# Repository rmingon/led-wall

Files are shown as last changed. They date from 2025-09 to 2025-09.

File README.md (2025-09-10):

# LED-Wall Tile — CH32V003 Parallel-Bus WS2812B Controller (5×5)

A modular **5×5 WS2812B LED tile** driven by a **CH32V003** slave MCU.  
Tiles share a simple **8-bit parallel bus + CLK + EN** so a Raspberry Pi (or any MCU) can address many tiles and push pixel data quickly.

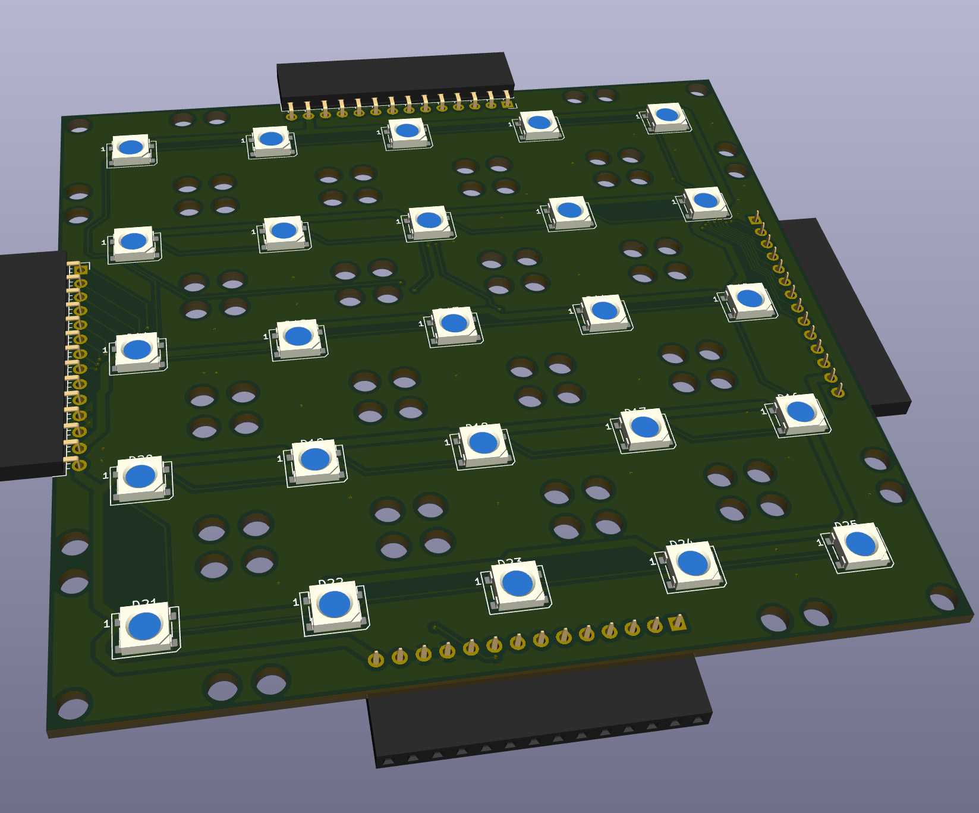
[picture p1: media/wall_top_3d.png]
3d

---

## Highlights

- **25× WS2812B** per tile (5 rows × 5 columns), daisy-chained on-board
- **Parallel control bus:** `DATA0…DATA7`, `CLK`, `EN`, optional `RST`
- **MCU:** WCH **CH32V003F…** (RISC-V, 3.3 V)
- **Power:** 5 V input for LEDs; onboard **AMS1117-3.3** LDO for the MCU
- **Connectors on four edges** for tiling/rotation; pass-through for power & bus
- **Status LED** on a GPIO for quick diagnostics
- Designed with **KiCad 9.0.3**

---

## Repo structure

```
/wall/
  wall.kicad_pro
  wall.kicad_pcb
  wall.kicad_sch
  wall.kicad_prl
/media/
  wall_top_3d.jpeg
  wall_bottom_3d.jpeg
  wall_pcb.png
  wall_schematic.png
/firmware/        # (placeholder) CH32V003 code
/tools/           # (placeholder) host examples (Raspberry Pi)
README.md
```

---

## Images

- Top 3D: `media/wall_top_3d.jpeg`
- Bottom 3D: `media/wall_bottom_3d.jpeg`
- PCB layout: `media/wall_pcb.png`
- Schematic: `media/wall_schematic.png`

---

## Electrical overview

- **LED matrix:** 25 × WS2812B (5050). Data is routed serpentine per row.
- **MCU:** `CH32V003F*P6` (labelled **U1** in the schematic).
  - Parallel data bus on **PC0…PC7**
  - `CLK` and `EN` on PDx pins (see net labels in schematic)
  - `PA1/PA2` used for the **WS2812** data output to the first LED in the chain
  - `RST` net broken out (optional external reset)
- **Power:**
  - **+5 V** for LEDs
  - **AMS1117-3.3** (U3) generates **+3V3** for the MCU; C1/C2/C3 for decoupling
- **Indicators:** D26 + R4 connected to a GPIO (status / heartbeat)

> ⚠️ **Current budget:** Each WS2812B can draw up to **40 mA** at full-white.  
> One tile worst-case ≈ **25 × 40 mA = 1.5 A @ 5 V** (plus margin).  
> Size your power rails accordingly and avoid sustained full-white if thermals are tight.

---

## Connectors / Pinout

Each edge header is a **1×14** connector carrying power and the parallel bus.

| Pin | Signal | Notes |
| --: | :----- | :--- |
| 1 | DATA0  | Parallel data bit 0 (MCU **PC0**)  |
| 2 | DATA1  | (PC1) |
| 3 | DATA2  | (PC2) |
| 4 | DATA3  | (PC3) |
| 5 | DATA4  | (PC4) |
| 6 | DATA5  | (PC5) |
| 7 | DATA6  | (PC6) |
| 8 | DATA7  | (PC7) |
| 9 | CLK | Rising edge latch (EXTI7_0 IRQ) |
|  10 | EN | Tile enable / latch (PDx) |
|  11 | GND | Ground |
|  12 | GND | Ground (second pin for current) |
|  13 | +5V | LED power |
|  14 | +5V | LED power (second pin for current) |

> Exact PDx assignments are labelled in the schematic nets; keep those in firmware defines so you can move them if the footprint changes.

- WS2812 data → **PC7 / TIM2_CH2 (remap)**
- Driven by **TIM2 PWM + DMA**

---

## Protocol

Each frame is transmitted as a sequence of **bytes** clocked on **PD2 rising edge** while the slave samples D0–D7.

**Frame format:**

```
SOF0 SOF1 ADDR CMD LEN PAY[LEN] CRC
```

- **SOF0** = `0xA5`
- **SOF1** = `0x5A`
- **ADDR** = 0–254 for unicast, `0xFF` for broadcast
- **CMD** = command byte
- **LEN** = number of payload bytes
- **PAY** = payload
- **CRC** = Dallas/Maxim CRC8 (poly=0x31 reflected=0x8C, init=0x00) computed over `ADDR..CMD..LEN..PAY`

### Commands

| CMD  | Name | LEN | Payload description |
| ---- | --- | --- | --- |
| 0x01 | `SET_ALL_RGB` | 3×N (75) | [R,G,B] triplets for all LEDs |
| 0x02 | `SET_ONE_RGB` | 4 | [index, R, G, B] (0–24 index) |
| 0x03 | `FILL_RGB` | 3 | [R, G, B] fill all LEDs |
| 0x04 | `BOOT_TEST` | 0 | Run built-in RGB test animation |

---

## Firmware (CH32V003)

- **Toolchain:** WCH-RISC-V (MounRiver) or Open-source (e.g., `riscv-none-elf-gcc` + `openocd` for WCH-LinkE).
- **Peripherals used:**
  - GPIO for `DATA[7:0]`, `CLK`, `EN`, `LED`
  - Timer or edge-detect to sample `CLK` while `EN=1`
  - Bit-banged or timer-driven WS2812 waveform output on `PAx`
- **WS2812 timing:** 800 kHz, 1.25 µs/bit. Use a timer and tight ISR/DMA-like loop to meet timing.

**Build steps (outline):**

1. Clone repo; open `/kicad/wall.kicad_pro` to view hardware.
2. Open `/wall_code/` in your IDE; set your tile address in `main.c`.
3. Flash with **WCH-LinkE** via **SWIO** (PD1 on CH32V003). Provide a small 3-pin tag-connector or pogo-pads on your programmer.
4. Power at 5 V and verify the heartbeat LED.

---

## Example Host Frame

Set all 25 LEDs to **red (255,0,0)**:

```
A5 5A 12 01 4B  FF 00 00 FF 00 00 ... (25 triplets) ... CRC
```

- `0xA5 0x5A` = SOF
- `0x12` = target address
- `0x01` = `SET_ALL_RGB`
- `0x4B` = 75 payload bytes
- Payload = 25× [FF,00,00]
- `CRC` = computed over ADDR..PAYLOAD

## Raspberry Pi example (Python, pseudo-code)

2. Open `host.py` in your IDE.

## Example Host Frame

Set all 25 LEDs to **red (255,0,0)**:

```
A5 5A 12 01 4B  FF 00 00 FF 00 00 ... (25 triplets) ... CRC
```

- `0xA5 0x5A` = SOF
- `0x12` = target address
- `0x01` = `SET_ALL_RGB`
- `0x4B` = 75 payload bytes
- Payload = 25× [FF,00,00]
- `CRC` = computed over ADDR..PAYLOAD

---

## Manufacturing notes

- **Layers:** 2-layer, 1.6 mm FR-4, 1 oz Cu
- **Min track/clearance:** per your fab defaults (design uses moderate widths)
- **Finish:** HASL or ENIG
- **Decoupling:** place 0.1 µF near the MCU VDD and each LED power rail segment
- **Mounting:** corner holes + through-grid holes in the LED field (for diffusion/weight).

---

## Bring-up checklist

1. Power at **5 V** and check **+3V3** out of U3 (AMS1117-3.3).
2. Flash firmware; confirm status LED blinks.
3. With a logic analyzer, verify `CLK` edges and that `DATA[7:0]` are stable at each edge while `EN=1`.
4. Send a **Fill** command to a single address → tile lights uniformly.
5. Push a full **75-byte** pixel buffer → verify 5×5 order matches your mapping.

---

## License

- Hardware: CC-BY-SA 4.0
- Firmware/Host code: MIT

---

## Credits

Designed by **RMINGON**.  
KiCad project files: `kicad/wall.*` (created with KiCad **9.0.3**).

---

### Bill-of-Materials (core)

| Ref | Part | Notes |
| --- | --- | --- |
| U1 | **CH32V003F…P6** | 3.3 V RISC-V MCU |
| U3 | **AMS1117-3.3** | 5 V → 3.3 V LDO |
| D1–D25  | **WS2812B** | 5 V addressable LEDs |
| D26, R4 | Status LED + 5 Ω–1 kΩ | (value per brightness; schematic shows **R4 5 Ω**) |
| J1–J4 | 1×14 headers | Bus + Power |
| C1–C3 | 10 µF/0.1 µF mix | Regulator & MCU decoupling |

> Tweak values to match your inventory and regulator stability requirements (e.g., AMS1117 likes ≥10 µF on input/output).

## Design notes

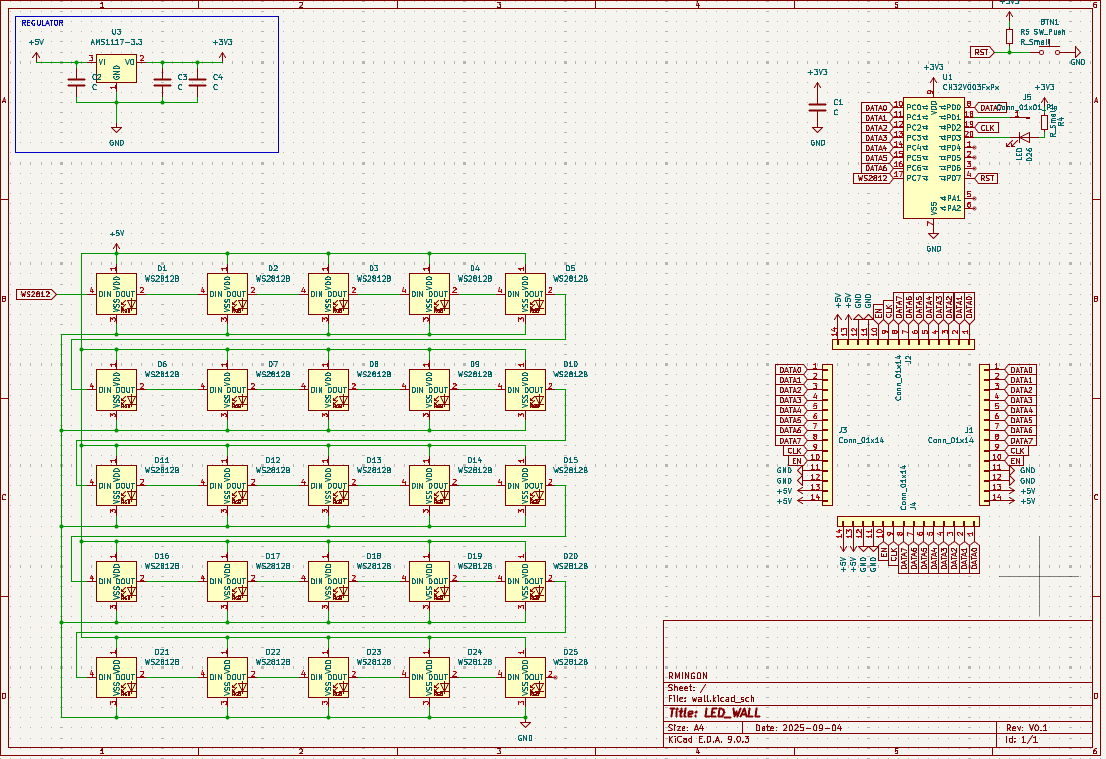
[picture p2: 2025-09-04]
media/wall_schematic.png

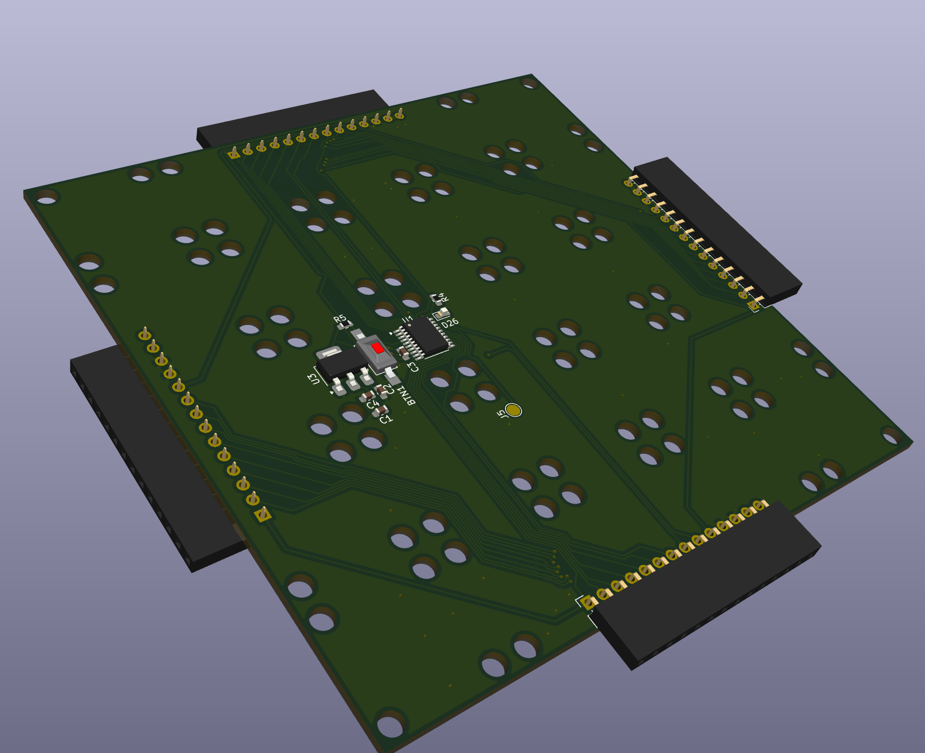
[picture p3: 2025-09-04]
media/wall_bottom_3d.png

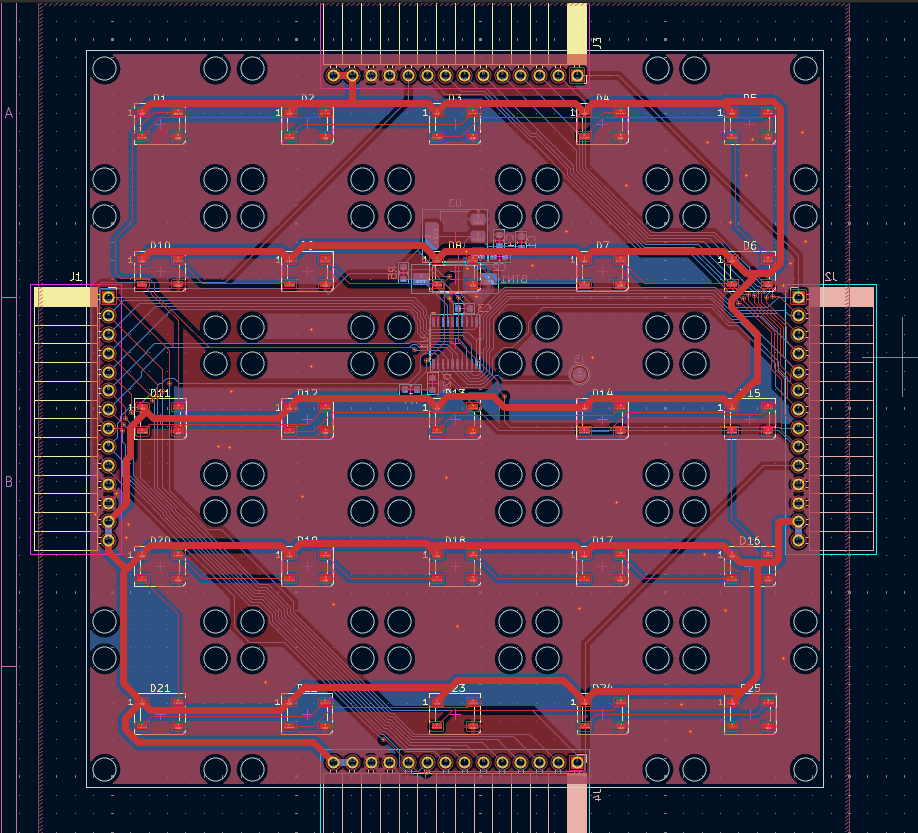
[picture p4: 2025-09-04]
media/wall_pcb.png

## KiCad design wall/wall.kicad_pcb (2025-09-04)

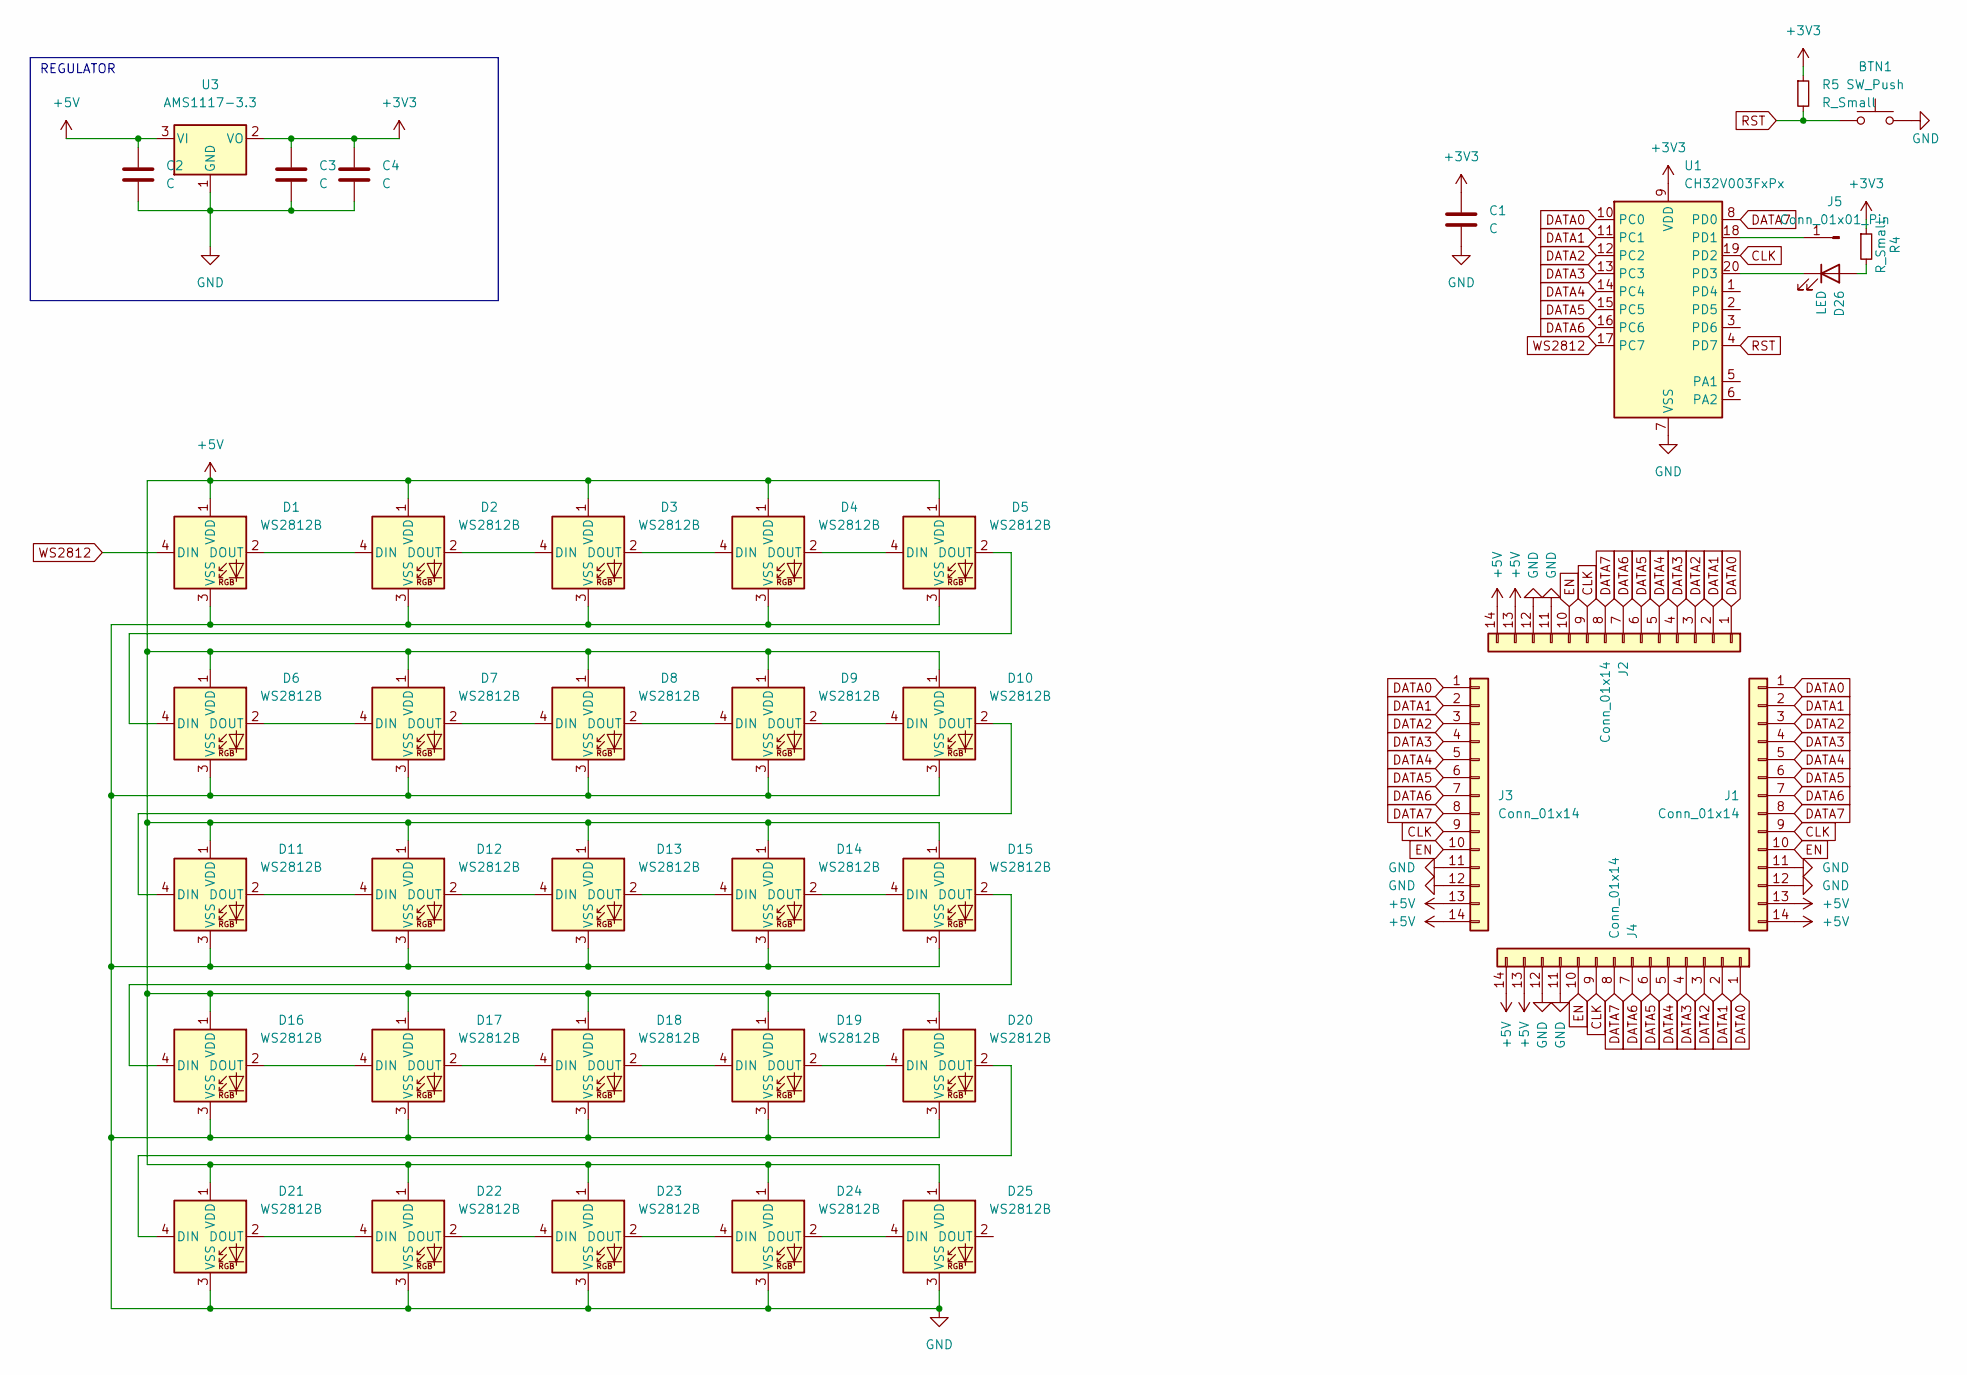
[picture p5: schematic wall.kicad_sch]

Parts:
BTN1: SW_Push; SW_SPST_FSMSM; LCSC C398053
C1, C2, C4: C; C_0603_1608Metric; LCSC C30926
C3: C; C_0603_1608Metric; LCSC C19702
D1, D2, D3, D4, D5, D6, D7, D8, D9, D10, D11, D12, D13, D14, D15, D16, D17, D18, D19, D20, D21, D22, D23, D24, D25: WS2812B; LED_WS2812B_PLCC4_5.0x5.0mm_P3.2mm
D26: LED; LED_0603_1608Metric; LCSC C19171301
J1, J2, J3, J4: Conn_01x14; PinSocket_1x14_P2.54mm_Horizontal
J5: Conn_01x01_Pin; TestPoint_Pad_D2.0mm
R4: R_Small; R_0603_1608Metric; LCSC C2906975
R5: R_Small; R_0603_1608Metric; LCSC C98220
U1: CH32V003FxPx; TSSOP-20_4.4x6.5mm_P0.65mm
U3: AMS1117-3.3; SOT-223-3_TabPin2; LCSC C6186

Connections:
+3V3: C1.1, C3.1, C4.1, R4.1, R5.1, U1.9 (VDD), U3.2 (VO)
+5V: C2.1, D1.1 (VDD), D2.1 (VDD), D3.1 (VDD), D4.1 (VDD), D5.1 (VDD), D6.1 (VDD), D7.1 (VDD), D8.1 (VDD), D9.1 (VDD), D10.1 (VDD), D11.1 (VDD), D12.1 (VDD), D13.1 (VDD), D14.1 (VDD), D15.1 (VDD), D16.1 (VDD), D17.1 (VDD), D18.1 (VDD), D19.1 (VDD), D20.1 (VDD), D21.1 (VDD), D22.1 (VDD), D23.1 (VDD), D24.1 (VDD), D25.1 (VDD), J1.13, J1.14, J2.13, J2.14, J3.13, J3.14, J4.13, J4.14, U3.3 (VI)
CLK: J1.9, J2.9, J3.9, J4.9, U1.19 (PD2)
DATA0: J1.1, J2.1, J3.1, J4.1, U1.10 (PC0)
DATA1: J1.2, J2.2, J3.2, J4.2, U1.11 (PC1)
DATA2: J1.3, J2.3, J3.3, J4.3, U1.12 (PC2)
DATA3: J1.4, J2.4, J3.4, J4.4, U1.13 (PC3)
DATA4: J1.5, J2.5, J3.5, J4.5, U1.14 (PC4)
DATA5: J1.6, J2.6, J3.6, J4.6, U1.15 (PC5)
DATA6: J1.7, J2.7, J3.7, J4.7, U1.16 (PC6)
DATA7: J1.8, J2.8, J3.8, J4.8, U1.8 (PD0)
EN: J1.10, J2.10, J3.10, J4.10
GND: BTN1.2, C1.2, C2.2, C3.2, C4.2, D1.3 (VSS), D2.3 (VSS), D3.3 (VSS), D4.3 (VSS), D5.3 (VSS), D6.3 (VSS), D7.3 (VSS), D8.3 (VSS), D9.3 (VSS), D10.3 (VSS), D11.3 (VSS), D12.3 (VSS), D13.3 (VSS), D14.3 (VSS), D15.3 (VSS), D16.3 (VSS), D17.3 (VSS), D18.3 (VSS), D19.3 (VSS), D20.3 (VSS), D21.3 (VSS), D22.3 (VSS), D23.3 (VSS), D24.3 (VSS), D25.3 (VSS), J1.11, J1.12, J2.11, J2.12, J3.11, J3.12, J4.11, J4.12, U1.7 (VSS), U3.1 (GND)
unnamed: D1.2 (DOUT), D2.4 (DIN)
unnamed: D2.2 (DOUT), D3.4 (DIN)
unnamed: D3.2 (DOUT), D4.4 (DIN)
unnamed: D4.2 (DOUT), D5.4 (DIN)
unnamed: D5.2 (DOUT), D6.4 (DIN)
unnamed: D6.2 (DOUT), D7.4 (DIN)
unnamed: D7.2 (DOUT), D8.4 (DIN)
unnamed: D8.2 (DOUT), D9.4 (DIN)
unnamed: D9.2 (DOUT), D10.4 (DIN)
unnamed: D10.2 (DOUT), D11.4 (DIN)
unnamed: D11.2 (DOUT), D12.4 (DIN)
unnamed: D12.2 (DOUT), D13.4 (DIN)
unnamed: D13.2 (DOUT), D14.4 (DIN)
unnamed: D14.2 (DOUT), D15.4 (DIN)
unnamed: D15.2 (DOUT), D16.4 (DIN)
unnamed: D16.2 (DOUT), D17.4 (DIN)
unnamed: D17.2 (DOUT), D18.4 (DIN)
unnamed: D18.2 (DOUT), D19.4 (DIN)
unnamed: D19.2 (DOUT), D20.4 (DIN)
unnamed: D20.2 (DOUT), D21.4 (DIN)
unnamed: D21.2 (DOUT), D22.4 (DIN)
unnamed: D22.2 (DOUT), D23.4 (DIN)
unnamed: D23.2 (DOUT), D24.4 (DIN)
unnamed: D24.2 (DOUT), D25.4 (DIN)
unnamed: D26.2 (A), R4.2
unnamed: D26.1 (K), U1.20 (PD3)
unnamed: J5.1, U1.18 (PD1)
RST: BTN1.1, R5.2, U1.4 (PD7)
WS2812: D1.4 (DIN), U1.17 (PC7)

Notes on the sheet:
REGULATOR

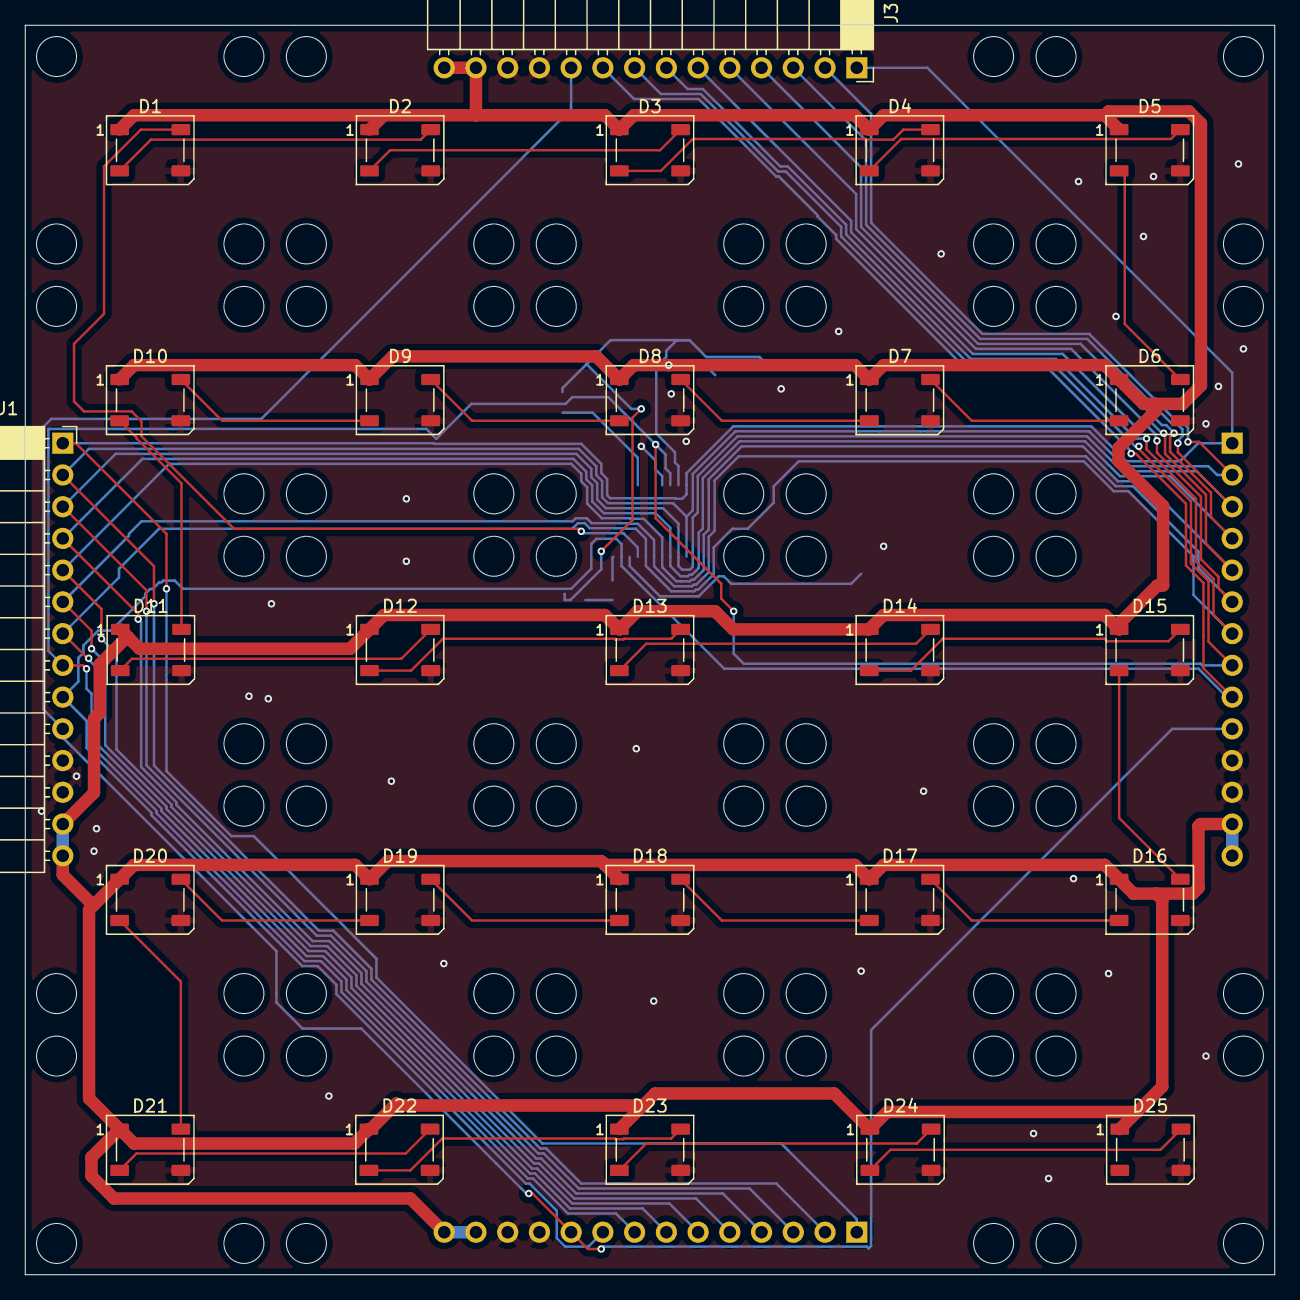
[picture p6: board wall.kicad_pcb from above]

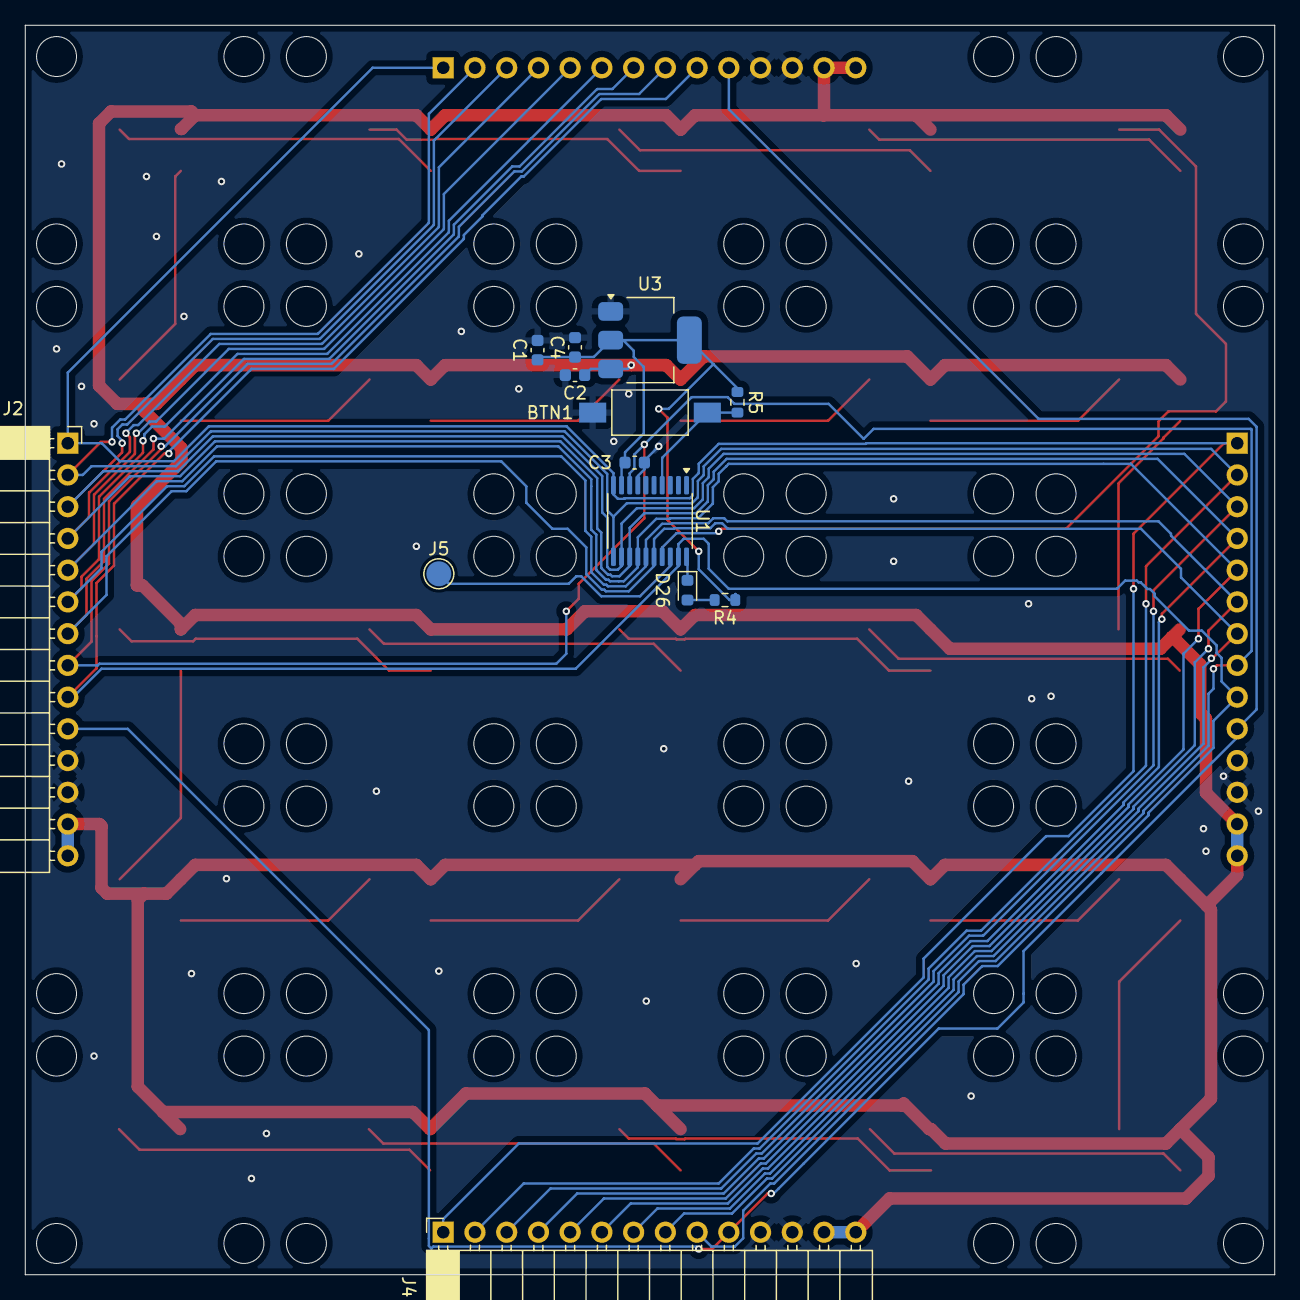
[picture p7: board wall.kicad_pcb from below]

Board: 2 copper layers, 100.0 x 100.0 mm, 40 parts (13 on the bottom side), 42 nets.

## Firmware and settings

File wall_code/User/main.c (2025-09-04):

/* ============================================================
 * CH32V006 SLAVE: WS2812 (PC7, TIM2+DMA) + 8-bit bus + address
 *  Data bus: PC0..PC6 = D0..D6, PD0 = D7
 *  Clock   : PD2 rising edge (EXTI lines 0..7 → EXTI7_0 IRQ)
 *  LEDs    : WS2812 on PC7 via TIM2_CH2 remap + DMA1 Channel2
 * ============================================================ */

#include "debug.h"
#include <stdint.h>
#include <string.h>

/* ==================== User configuration ==================== */
#define DEVICE_ADDR   0x12      /* 0..254 unique per node; 0xFF is broadcast */
#define NUM_LEDS      25        
#define BIT_TICKS   60u
#define TICKS_0     18u
#define TICKS_1     38u

/* ==================== Protocol (framed + addressed) ==========
 * Frame bytes: A5 5A ADDR CMD LEN PAY[LEN] CRC
 * ADDR: 0..254 unicast, 0xFF broadcast
 * CRC : Dallas/Maxim CRC8 (poly 0x31 reflected → 0x8C), init 0x00,
 *       over ADDR..CMD..LEN..PAYLOAD
 * Commands:
 *  0x01 SET_ALL_RGB : LEN=3*N, payload RGB triplets
 *  0x02 SET_ONE_RGB : LEN=4, payload idx,R,G,B
 *  0x03 FILL_RGB    : LEN=3, payload R,G,B
 *  0x04 BOOT_TEST   : LEN=0
 * ============================================================ */
#define SOF0  0xA5
#define SOF1  0x5A
#define ADDR_BCAST 0xFF

#define CMD_SET_ALL_RGB  0x01
#define CMD_SET_ONE_RGB  0x02
#define CMD_FILL_RGB     0x03
#define CMD_BOOT_TEST    0x04

static uint8_t  ws_grb[NUM_LEDS][3];
static uint16_t ws_ccr[NUM_LEDS * 24];

static void WS_encode(void) {
    size_t k = 0;
    for (size_t i = 0; i < NUM_LEDS; ++i) {
        /* GRB order expected by WS2812 */
        const uint8_t c[3] = { ws_grb[i][0], ws_grb[i][1], ws_grb[i][2] };
        for (int ch = 0; ch < 3; ++ch) {
            uint8_t v = c[ch];
            for (int b = 7; b >= 0; --b) {
                ws_ccr[k++] = ((v >> b) & 1) ? TICKS_1 : TICKS_0;
            }
        }
    }
}

/* Remap TIM2_CH2 → PC7; set PC7 AF-PP; configure TIM2 + UDE */
static void WS_LL_Init(void) {
    RCC->PB2PCENR |= (1u<<0) /*AFIOEN*/ | (1u<<4) /*IOPCEN*/;
    RCC->PB1PCENR |= (1u<<0) /*TIM2EN*/;
    RCC->HBPCENR  |= (1u<<0) /*DMA1EN*/;

    AFIO->PCFR1 = (AFIO->PCFR1 & ~(0x7u << 14)) | (0x3u << 14);

    /* PC7 = AF push-pull, 30 MHz */
    GPIOC->CFGLR &= ~(0xFu << (7*4));
    GPIOC->CFGLR |=  (0xBu << (7*4)); /* MODE=11, CNF=10 */

    TIM2->PSC   = 0;
    TIM2->ATRLR = BIT_TICKS - 1;
    TIM2->CNT   = 0;

    TIM2->CHCTLR1 &= ~(0xFFu << 8);
    TIM2->CHCTLR1 |=  (6u << 12); /* OC2M=110 PWM1 */
    TIM2->CHCTLR1 |=  (1u << 11); /* OC2PE=1 */
    TIM2->CCER    &= ~(1u << 5);  /* CC2P=0 */
    TIM2->CCER    |=  (1u << 4);  /* CC2E=1 */

    TIM2->CTLR1   |=  (1u << 7);  /* ARPE */
    TIM2->SWEVGR   =  1u;         /* UG */

    /* Update DMA request enable (one write to CCR2 each period) */
    TIM2->DMAINTENR |= (1u << 8); /* UDE */
}

static void WS_DMA_Start(uint16_t *src, uint16_t count) {
    DMA1_Channel2->CFGR &= ~1u; /* EN=0 */

    DMA1_Channel2->PADDR = (uint32_t)&TIM2->CH2CVR; /* dest = CCR2 */
    DMA1_Channel2->MADDR = (uint32_t)src;
    DMA1_Channel2->CNTR  = count;

    uint32_t cfg = 0;
    cfg |= (0u<<14); /* MEM2MEM=0 */
    cfg |= (2u<<12); /* High priority */
    cfg |= (1u<<10); /* MSIZE=16-bit */
    cfg |= (1u<< 8); /* PSIZE=16-bit */
    cfg |= (1u<< 7); /* MINC=1 */
    cfg |= (0u<< 6); /* PINC=0 */
    cfg |= (1u<< 4); /* DIR=1 (mem→periph) */
    cfg |= (0u<< 3); /* CIRC=0 */
    cfg |= (0u<< 1); /* TCIE=0 (poll) */
    DMA1_Channel2->CFGR = cfg;

    DMA_ClearFlag(DMA1_FLAG_TC2);
    DMA1_Channel2->CFGR |= 1u; /* EN=1 */
}

static inline void WS_SetPixel_RGB(size_t i, uint8_t r, uint8_t g, uint8_t b) {
    if (i >= NUM_LEDS) return;
    ws_grb[i][0] = g; ws_grb[i][1] = r; ws_grb[i][2] = b;
}

static void WS_BootTest(void) {
    for (size_t i = 0; i < NUM_LEDS; i++) {
        for (size_t j = 0; j < NUM_LEDS; j++) WS_SetPixel_RGB(j, 0, 0, 0);

        WS_SetPixel_RGB(i, 255, 0, 0); WS_encode(); WS_DMA_Start(ws_ccr, (uint16_t)(NUM_LEDS*24));
        TIM2->SWEVGR = 1u; TIM2->CTLR1 |= 1u;
        while (DMA_GetFlagStatus(DMA1_FLAG_TC2) == RESET) {}
        DMA_ClearFlag(DMA1_FLAG_TC2);
        DMA1_Channel2->CFGR &= ~1u; TIM2->DMAINTENR &= ~(1u<<8);
        TIM2->CH2CVR = 0; TIM2->SWEVGR = 1u; Delay_Ms(200);
        TIM2->CTLR1 &= ~1u; TIM2->DMAINTENR |= (1u<<8);

        WS_SetPixel_RGB(i, 0, 255, 0); WS_encode(); WS_DMA_Start(ws_ccr, (uint16_t)(NUM_LEDS*24));
        TIM2->SWEVGR = 1u; TIM2->CTLR1 |= 1u;
        while (DMA_GetFlagStatus(DMA1_FLAG_TC2) == RESET) {}
        DMA_ClearFlag(DMA1_FLAG_TC2);
        DMA1_Channel2->CFGR &= ~1u; TIM2->DMAINTENR &= ~(1u<<8);
        TIM2->CH2CVR = 0; TIM2->SWEVGR = 1u; Delay_Ms(200);
        TIM2->CTLR1 &= ~1u; TIM2->DMAINTENR |= (1u<<8);

        WS_SetPixel_RGB(i, 0, 0, 255); WS_encode(); WS_DMA_Start(ws_ccr, (uint16_t)(NUM_LEDS*24));
        TIM2->SWEVGR = 1u; TIM2->CTLR1 |= 1u;
        while (DMA_GetFlagStatus(DMA1_FLAG_TC2) == RESET) {}
        DMA_ClearFlag(DMA1_FLAG_TC2);
        DMA1_Channel2->CFGR &= ~1u; TIM2->DMAINTENR &= ~(1u<<8);
        TIM2->CH2CVR = 0; TIM2->SWEVGR = 1u; Delay_Ms(200);
        TIM2->CTLR1 &= ~1u; TIM2->DMAINTENR |= (1u<<8);

        WS_SetPixel_RGB(i, 0, 0, 0); WS_encode(); WS_DMA_Start(ws_ccr, (uint16_t)(NUM_LEDS*24));
        TIM2->SWEVGR = 1u; TIM2->CTLR1 |= 1u;
        while (DMA_GetFlagStatus(DMA1_FLAG_TC2) == RESET) {}
        DMA_ClearFlag(DMA1_FLAG_TC2);
        DMA1_Channel2->CFGR &= ~1u; TIM2->DMAINTENR &= ~(1u<<8);
        TIM2->CH2CVR = 0; TIM2->SWEVGR = 1u; Delay_Ms(120);
        TIM2->CTLR1 &= ~1u; TIM2->DMAINTENR |= (1u<<8);
    }
}

static void WS_Show(void) {
    WS_encode();
    WS_DMA_Start(ws_ccr, (uint16_t)(NUM_LEDS*24));

    TIM2->SWEVGR = 1u;   /* UG */
    TIM2->CTLR1 |= 1u;   /* CEN */

    while (DMA_GetFlagStatus(DMA1_FLAG_TC2) == RESET) {}
    DMA_ClearFlag(DMA1_FLAG_TC2);

    DMA1_Channel2->CFGR &= ~1u;        /* EN=0 */
    TIM2->DMAINTENR     &= ~(1u<<8);   /* UDE=0 */
    TIM2->CH2CVR = 0;                  /* duty=0 → low */
    TIM2->SWEVGR = 1u;                 /* latch */
    Delay_Us(100);
    TIM2->CTLR1 &= ~1u;                /* stop */
    TIM2->DMAINTENR |= (1u<<8);        /* re-arm */
}

/* ============================================================
 *                   Parallel bus + framing
 *  Data: PC0..6 = D0..D6, PD0 = D7
 *  Clock: PD2 rising edge → EXTI7_0_IRQHandler
 * ============================================================ */
#define RX_MAX (3*NUM_LEDS + 8)

typedef enum { RX_SOF0, RX_SOF1, RX_ADDR, RX_CMD, RX_LEN, RX_PAY, RX_CRC } rx_state_t;
static volatile rx_state_t rx_state = RX_SOF0;

static volatile uint8_t  rx_addr=0, rx_cmd=0, rx_len=0, rx_crc=0;
static volatile uint8_t  rx_pay[RX_MAX];
static volatile uint16_t rx_idx=0;
static volatile uint8_t  frame_ready=0;

/* CRC8 Dallas/Maxim (reflected 0x31 → 0x8C) init 0x00 */
static uint8_t crc8_maxim(const uint8_t *p, size_t n){
    uint8_t crc = 0x00;
    while (n--){
        uint8_t in = *p++;
        for (uint8_t i=0;i<8;i++){
            uint8_t mix = (crc ^ in) & 0x01;
            crc >>= 1;
            if (mix) crc ^= 0x8C;
            in >>= 1;
        }
    }
    return crc;
}

/* Read D[7:0] : PC0..6→D0..6, PD0→D7 */
static inline uint8_t BUS_ReadByte(void){
    uint32_t c = GPIOC->INDR;
    uint32_t d = GPIOD->INDR;
    uint8_t v  = (uint8_t)(c & 0x7Fu);
    v |= (uint8_t)((d & 0x1u) << 7);
    return v;
}

/* Configure inputs + EXTI on PD2 */
static void ParallelBus_Init(void){
    RCC_PB2PeriphClockCmd(RCC_PB2Periph_AFIO | RCC_PB2Periph_GPIOC | RCC_PB2Periph_GPIOD, ENABLE);

    GPIO_InitTypeDef io = {0};

    io.GPIO_Pin  = GPIO_Pin_0 | GPIO_Pin_1 | GPIO_Pin_2 | GPIO_Pin_3 |
                   GPIO_Pin_4 | GPIO_Pin_5 | GPIO_Pin_6;
    io.GPIO_Mode = GPIO_Mode_IPU;
    GPIO_Init(GPIOC, &io);

    io.GPIO_Pin  = GPIO_Pin_0 | GPIO_Pin_2;
    io.GPIO_Mode = GPIO_Mode_IPU;
    GPIO_Init(GPIOD, &io);

    GPIO_EXTILineConfig(GPIO_PortSourceGPIOD, GPIO_PinSource2);

    EXTI_InitTypeDef ex = {0};
    ex.EXTI_Line    = EXTI_Line2;
    ex.EXTI_Mode    = EXTI_Mode_Interrupt;
    ex.EXTI_Trigger = EXTI_Trigger_Rising;
    ex.EXTI_LineCmd = ENABLE;
    EXTI_Init(&ex);

    NVIC_InitTypeDef nv = {0};
    nv.NVIC_IRQChannel                   = EXTI7_0_IRQn; /* lines 0..7 share irq */
    nv.NVIC_IRQChannelPreemptionPriority = 1;
    nv.NVIC_IRQChannelSubPriority        = 1;
    nv.NVIC_IRQChannelCmd                = ENABLE;
    NVIC_Init(&nv);
}

/* EXTI lines 0..7 ISR (PD2 rising) */
void EXTI7_0_IRQHandler(void){
    if (EXTI_GetITStatus(EXTI_Line2) != RESET){
        uint8_t b = BUS_ReadByte();

        switch (rx_state){
        case RX_SOF0:
            rx_state = (b == SOF0) ? RX_SOF1 : RX_SOF0;
            break;
        case RX_SOF1:
            rx_state = (b == SOF1) ? RX_ADDR : RX_SOF0;
            break;
        case RX_ADDR:
            rx_addr = b; rx_state = RX_CMD; break;
        case RX_CMD:
            rx_cmd  = b; rx_state = RX_LEN; break;
        case RX_LEN:
            rx_len = b; rx_idx = 0;
            if (rx_len > (RX_MAX-8)) { rx_state = RX_SOF0; break; }
            rx_state = (rx_len ? RX_PAY : RX_CRC);
            break;
        case RX_PAY:
            rx_pay[rx_idx++] = b;
            if (rx_idx >= rx_len) rx_state = RX_CRC;
            break;
        case RX_CRC: {
            rx_crc = b;
            uint8_t hdr[3] = { rx_addr, rx_cmd, rx_len };
            uint8_t crc = crc8_maxim(hdr, 3);
            crc = crc8_maxim(rx_pay, rx_len) ^ crc;
            if (crc == rx_crc) frame_ready = 1;
            rx_state = RX_SOF0;
            } break;
        }

        EXTI_ClearITPendingBit(EXTI_Line2);
    }
}

/* Execute a validated frame in main context */
static void ExecFrame(void){
    if (!(rx_addr == ADDR_BCAST || rx_addr == DEVICE_ADDR)) {
        frame_ready = 0; return; /* not for us */
    }

    switch (rx_cmd){
    case CMD_SET_ALL_RGB:
        if (rx_len == 3*NUM_LEDS){
            for (size_t i=0, j=0; i<NUM_LEDS; i++, j+=3){
                WS_SetPixel_RGB(i, rx_pay[j+0], rx_pay[j+1], rx_pay[j+2]);
            }
            WS_Show();
        }
        break;

    case CMD_SET_ONE_RGB:
        if (rx_len == 4){
            uint8_t idx = rx_pay[0];
            if (idx < NUM_LEDS){
                WS_SetPixel_RGB(idx, rx_pay[1], rx_pay[2], rx_pay[3]);
                WS_Show();
            }
        }
        break;

    case CMD_FILL_RGB:
        if (rx_len == 3){
            for (size_t i=0; i<NUM_LEDS; i++)
                WS_SetPixel_RGB(i, rx_pay[0], rx_pay[1], rx_pay[2]);
            WS_Show();
        }
        break;

    case CMD_BOOT_TEST:
        WS_BootTest();
        break;

    default:
        /* ignore unknown */
        break;
    }

    frame_ready = 0;
}

/* ============================== main ============================== */
int main(void){
    SystemInit();
    Delay_Init();

    WS_LL_Init();        /* PC7 TIM2+DMA driver ready */
    ParallelBus_Init();  /* PD2 clock, PC0..6+PD0 data */

    WS_BootTest();       /* power-on self-test */

    while (1){
        if (frame_ready) ExecFrame();
        /* __WFI(); // optional low-power */
    }
}

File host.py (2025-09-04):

# host_send.py
# Raspberry Pi → LED tiles (CH32V006 slave)
# Bus: DATA[0..7] on GPIO, CLK on GPIO (rising edge latch)
# Frame: A5 5A ADDR CMD LEN PAY[LEN] CRC (CRC8 Dallas/Maxim)

import time
import RPi.GPIO as GPIO

# ---------- Pin mapping (BCM) ----------
DATA_PINS = [5, 6, 13, 19, 26, 16, 20, 21]  # D0..D7
CLK_PIN   = 18                               # CLK (rising edge)

# ---------- Protocol constants ----------
SOF0, SOF1 = 0xA5, 0x5A
CMD_SET_ALL_RGB = 0x01
CMD_SET_ONE_RGB = 0x02
CMD_FILL_RGB    = 0x03
CMD_BOOT_TEST   = 0x04

ADDR_BCAST = 0xFF
NUM_LEDS   = 25

# ---------- Low-level bus ----------
def bus_init():
    GPIO.setmode(GPIO.BCM)
    for p in DATA_PINS:
        GPIO.setup(p, GPIO.OUT, initial=GPIO.LOW)
    GPIO.setup(CLK_PIN, GPIO.OUT, initial=GPIO.LOW)

def bus_cleanup():
    GPIO.cleanup()

def clock_byte(b: int, t_high=0.000002, t_low=0.000002):
    """Put b on DATA[7:0], then generate a CLK rising edge.
       t_high / t_low can be tuned if needed (seconds)."""
    for i, p in enumerate(DATA_PINS):   # D0..D7
        GPIO.output(p, (b >> i) & 1)
    GPIO.output(CLK_PIN, 1)
    # Short delays keep edges clean; adjust/omit if your wiring is short
    time.sleep(t_high)
    GPIO.output(CLK_PIN, 0)
    time.sleep(t_low)

# ---------- CRC8 Dallas/Maxim (reflected, poly 0x31 → 0x8C) ----------
def crc8_maxim(buf: bytes) -> int:
    crc = 0x00
    for x in buf:
        cur = x
        for _ in range(8):
            mix = (crc ^ cur) & 0x01
            crc >>= 1
            if mix:
                crc ^= 0x8C
            cur >>= 1
    return crc

# ---------- Framing ----------
def send_frame(addr: int, cmd: int, payload: bytes = b""):
    """Build + transmit one framed packet (address-aware)."""
    if not (0 <= addr <= 0xFF):
        raise ValueError("addr must be 0..255")
    if not (0 <= cmd <= 0xFF):
        raise ValueError("cmd must be 0..255")
    if not (0 <= len(payload) <= 255):
        raise ValueError("payload too long")

    # header + CRC
    header = bytes([addr, cmd, len(payload)])
    c = crc8_maxim(header)
    c ^= crc8_maxim(payload)  # CRC over ADDR..CMD..LEN..PAY
    frame = bytes([SOF0, SOF1]) + header + payload + bytes([c])

    # transmit
    for b in frame:
        clock_byte(b)

# ---------- High-level helpers ----------
def fill(addr: int, r: int, g: int, b: int):
    send_frame(addr, CMD_FILL_RGB, bytes([r & 0xFF, g & 0xFF, b & 0xFF]))

def set_one(addr: int, index: int, r: int, g: int, b: int):
    if not (0 <= index < NUM_LEDS):
        raise ValueError("index 0..24")
    send_frame(addr, CMD_SET_ONE_RGB, bytes([index & 0xFF, r & 0xFF, g & 0xFF, b & 0xFF]))

def set_all(addr: int, rgb_triples):
    """rgb_triples: iterable of (r,g,b), length == NUM_LEDS"""
    if len(rgb_triples) != NUM_LEDS:
        raise ValueError(f"need {NUM_LEDS} RGB tuples")
    pay = bytearray()
    for (r, g, b) in rgb_triples:
        pay += bytes([r & 0xFF, g & 0xFF, b & 0xFF])
    send_frame(addr, CMD_SET_ALL_RGB, bytes(pay))

def boot_test(addr: int):
    send_frame(addr, CMD_BOOT_TEST, b"")

# ---------- Example usage ----------
if __name__ == "__main__":
    try:
        bus_init()

        # broadcast fill to all tiles:
        fill(ADDR_BCAST, 0, 0, 0)                   # all off
        time.sleep(0.05)
        fill(ADDR_BCAST, 20, 0, 0)                  # dim red
        time.sleep(0.2)
        fill(ADDR_BCAST, 0, 20, 0)                  # dim green
        time.sleep(0.2)
        fill(ADDR_BCAST, 0, 0, 20)                  # dim blue
        time.sleep(0.2)

        # unicast examples:
        TILE = 0x12                                  # your node address
        boot_test(TILE)                              # run the slave's test
        time.sleep(0.5)

        # set one pixel on TILE to white:
        set_one(TILE, index=7, r=60, g=60, b=60)

        # set all pixels on TILE to a gradient:
        grad = [(i*10 % 256, i*5 % 256, i*3 % 256) for i in range(NUM_LEDS)]
        set_all(TILE, grad)

    finally:
        bus_cleanup()

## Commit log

2025-07-20 add wall schematic + pcb
    [wall.kicad_pcb, wall.kicad_sch]
2025-09-04 fix wall pcb
    [hardware.kicad_pcb, hardware.kicad_sch]
2025-09-04 create code for ch32v006 ws2812 control
    [wall.kicad_pcb]
